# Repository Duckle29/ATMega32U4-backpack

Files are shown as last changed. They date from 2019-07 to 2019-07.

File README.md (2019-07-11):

This is a small backpack PCB, meant to go with some 2.4" I2C OLED LCD. It exposes ALL pins on the ATMega32U4, so can be used for pretty much anything.

## Pinout:

| Pin | Encoder |  UART  | I2C  | WS2812 | SPI | CS3V3 |
|:---:|:---:|:---:|:---:|:---:|:---:|:---:|
|  1  | GND | GND  | GND  | GND  | MISO | 3V3 shifted IO (B0) |
|  2  | B | TX-3V3 | 5V |  Data  | 3V3 | |
|  3  | A | RX | SCL-5V | 5V |  SCK-3V3 | |
|  4  | SW |  5V in | SDA-5V | | MOSI-3V3 | |
|  5  | | | | | Reset  | |
|  6  | | | | | GND | |

The remaining pins are broken out on the back, with their port and number listed.

On the bottom is a micro-B USB.

**R4 and R5**  
Are I2C pullups. Attach these only if no other I2C device has pullups on them already.

**R6 and R7**  
Are optional pull-ups for the encoder. These can help if you have a noisy signal due to the weak internal pullups of the IC.

**Power**  
If the board is powered through the USB, the 5v power limit is 100mA, as it passes through D1. This is done to enable the chip to test if it's powered through USB or not.

```C
bool has_usb(void) {
  /* return (UDADDR & _BV(ADDEN)); */
   USBCON |= (1 << OTGPADE); // enables VBUS pad
   _delay_us(5);
   return (USBSTA & (1<<VBUS));  // checks state of VBUS
}
```

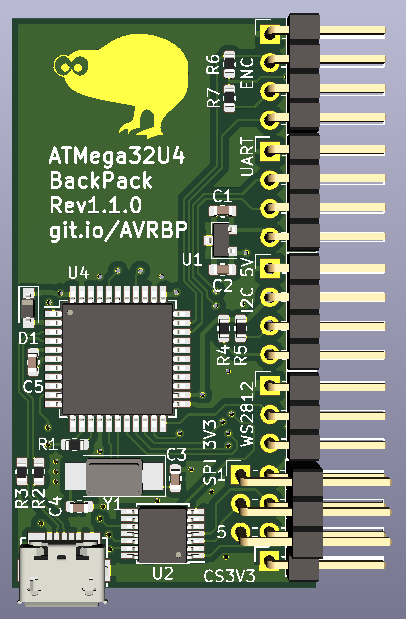
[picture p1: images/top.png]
top render

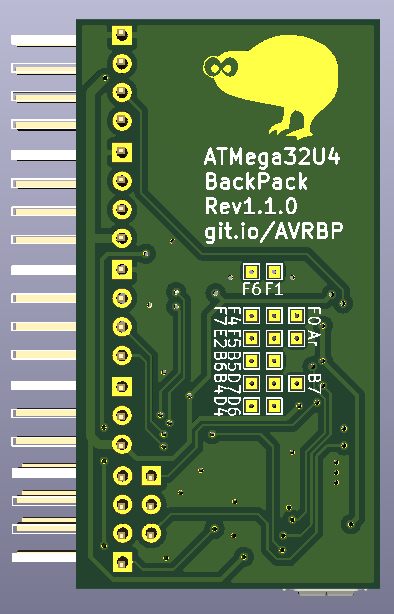
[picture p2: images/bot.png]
bot render


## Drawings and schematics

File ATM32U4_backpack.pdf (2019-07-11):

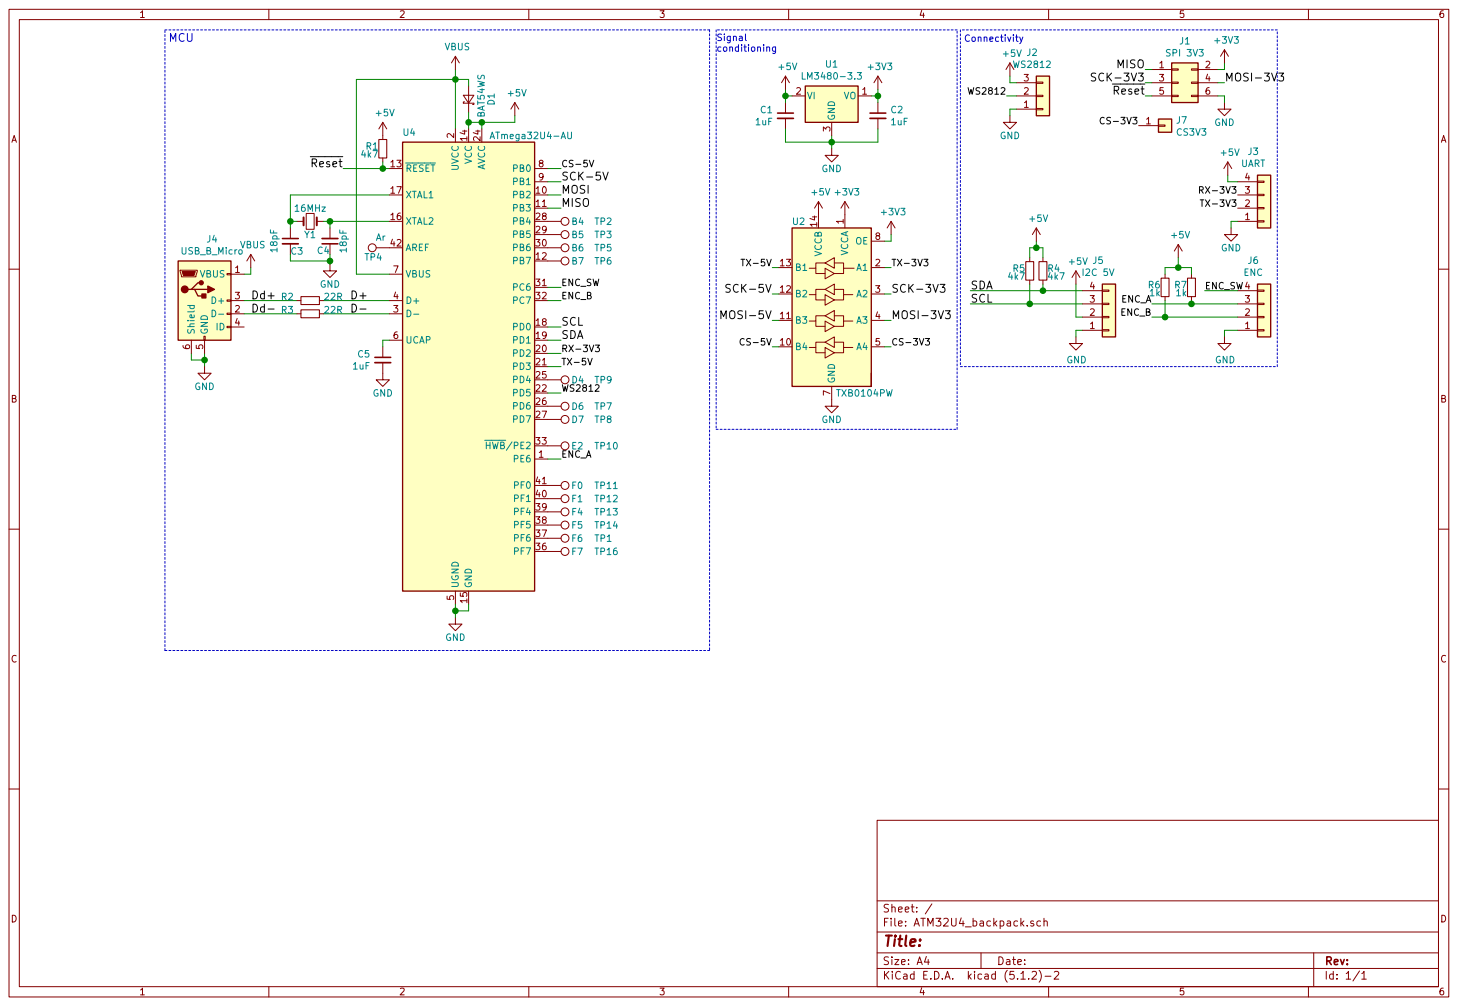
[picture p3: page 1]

2 PD2 20 PD3 21 PD5 22 AVCC 24 PD4 25 PD6 26 PD7 27 PB4 28 PB5 29 D- 3 PB6 30 PC6 31 PC7 32 HWB/PE2 33 PF7 36 PF6 37 PF5 38 PF4 39 D+ 4 PF1 40 PF0 41 AREF 42 UGND

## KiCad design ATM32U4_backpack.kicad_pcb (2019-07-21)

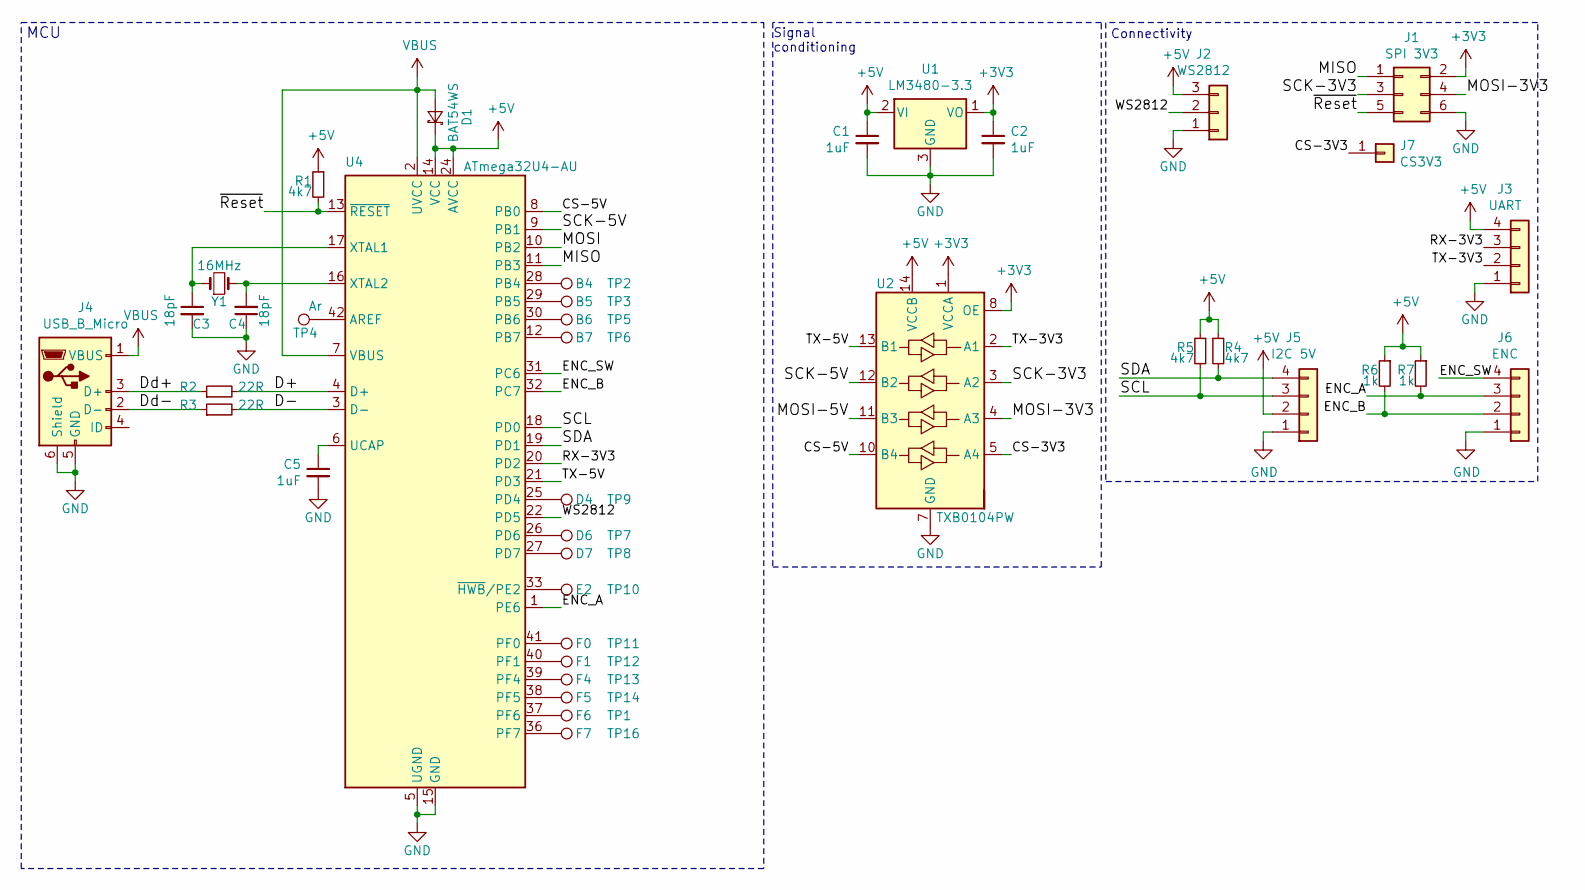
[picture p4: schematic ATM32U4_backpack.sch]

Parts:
C1, C2, C5: 1uF; C_0603_1608Metric
C3, C4: 18pF; C_0603_1608Metric
D1: BAT54WS; D_SOD-323_HandSoldering
J1: SPI 3V3; PinHeader_2x03_P2.54mm_Horizontal
J2: WS2812; PinHeader_1x03_P2.54mm_Horizontal
J3: UART; PinHeader_1x04_P2.54mm_Horizontal
J4: USB_B_Micro; USB_Micro-B_Molex_47346-0001
J5: I2C 5V; PinHeader_1x04_P2.54mm_Horizontal
J6: ENC; PinHeader_1x04_P2.54mm_Horizontal
J7: CS3V3; PinHeader_1x01_P2.54mm_Horizontal
R1, R4, R5: 4k7; R_0603_1608Metric
R2, R3: 22R; R_0603_1608Metric
R6, R7: 1k; R_0603_1608Metric
TP1: F6; TestPoint_Pad_1.0x1.0mm
TP2: B4; TestPoint_Pad_1.0x1.0mm
TP3: B5; TestPoint_Pad_1.0x1.0mm
TP4: Ar; TestPoint_Pad_1.0x1.0mm
TP5: B6; TestPoint_Pad_1.0x1.0mm
TP6: B7; TestPoint_Pad_1.0x1.0mm
TP7: D6; TestPoint_Pad_1.0x1.0mm
TP8: D7; TestPoint_Pad_1.0x1.0mm
TP9: D4; TestPoint_Pad_1.0x1.0mm
TP10: E2; TestPoint_Pad_1.0x1.0mm
TP11: F0; TestPoint_Pad_1.0x1.0mm
TP12: F1; TestPoint_Pad_1.0x1.0mm
TP13: F4; TestPoint_Pad_1.0x1.0mm
TP14: F5; TestPoint_Pad_1.0x1.0mm
TP16: F7; TestPoint_Pad_1.0x1.0mm
U1: LM3480-3.3; SOT-23
U2: TXB0104PW; TSSOP-14_4.4x5mm_P0.65mm
U4: ATmega32U4-AU; TQFP-44_10x10mm_P0.8mm
Y1: 16MHz; Crystal_SMD_5032-2Pin_5.0x3.2mm_HandSoldering

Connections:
+3V3: C2.1, J1.2, U1.1 (VO), U2.1 (VCCA), U2.8 (OE)
+5V: C1.1, D1.1 (K), J2.3, J3.4, J5.2, R1.1, R4.1, R5.1, R6.1, R7.1, U1.2 (VI), U2.14 (VCCB), U4.14 (VCC), U4.24 (AVCC), U4.34 (VCC), U4.44 (AVCC)
/CS-3V3: J7.1, U2.5 (A4)
/CS-5V: U2.10 (B4), U4.8 (PB0)
/D+: R2.2, U4.4 (D+)
/D-: R3.2, U4.3 (D-)
/Dd+: J4.3 (D+), R2.1
/Dd-: J4.2 (D-), R3.1
/ENC_A: J6.3, R7.2, U4.1 (PE6)
/ENC_B: J6.2, R6.2, U4.32 (PC7)
/ENC_SW: J6.4, U4.31 (PC6)
/MISO: J1.1, U4.11 (PB3)
/MOSI-3V3: J1.4, U2.4 (A3)
/RX-3V3: J3.3, U4.20 (PD2)
/SCK-3V3: J1.3, U2.3 (A2)
/SCK-5V: U2.12 (B2), U4.9 (PB1)
/SCL: J5.3, R5.2, U4.18 (PD0)
/SDA: J5.4, R4.2, U4.19 (PD1)
/TX-3V3: J3.2, U2.2 (A1)
/TX-5V: U2.13 (B1), U4.21 (PD3)
/WS2812: J2.2, U4.22 (PD5)
/~Reset: J1.5, R1.2, U4.13 (~RESET)
GND: C1.2, C2.2, C3.2, C4.1, C5.2, J1.6, J2.1, J3.1, J4.5 (GND), J4.6 (Shield), J5.1, J6.1, U1.3 (GND), U2.7 (GND), U4.5 (UGND), U4.15 (GND), U4.23 (GND), U4.35 (GND), U4.43 (GND)
unnamed: C3.1, U4.17 (XTAL1), Y1.1
unnamed: C4.2, U4.16 (XTAL2), Y1.2
unnamed: C5.1, U4.6 (UCAP)
unnamed: TP1.1, U4.37 (PF6)
unnamed: TP2.1, U4.28 (PB4)
unnamed: TP3.1, U4.29 (PB5)
unnamed: TP4.1, U4.42 (AREF)
unnamed: TP5.1, U4.30 (PB6)
unnamed: TP6.1, U4.12 (PB7)
unnamed: TP7.1, U4.26 (PD6)
unnamed: TP8.1, U4.27 (PD7)
unnamed: TP9.1, U4.25 (PD4)
unnamed: TP10.1, U4.33 (~HWB~/PE2)
unnamed: TP11.1, U4.41 (PF0)
unnamed: TP12.1, U4.40 (PF1)
unnamed: TP13.1, U4.39 (PF4)
unnamed: TP14.1, U4.38 (PF5)
unnamed: TP16.1, U4.36 (PF7)
VBUS: D1.2 (A), J4.1 (VBUS), U4.2 (UVCC), U4.7 (VBUS)

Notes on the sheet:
MCU
Signal conditioning
Connectivity

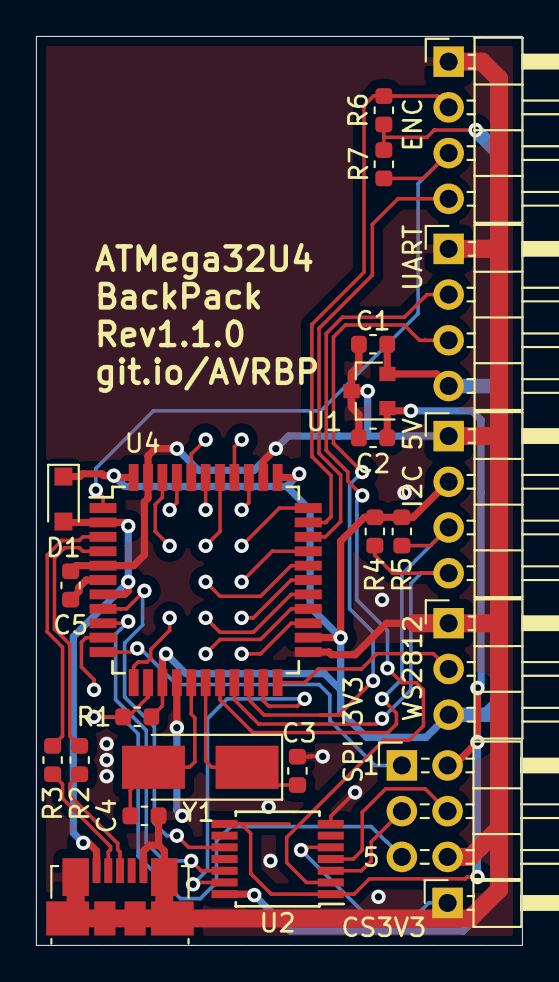
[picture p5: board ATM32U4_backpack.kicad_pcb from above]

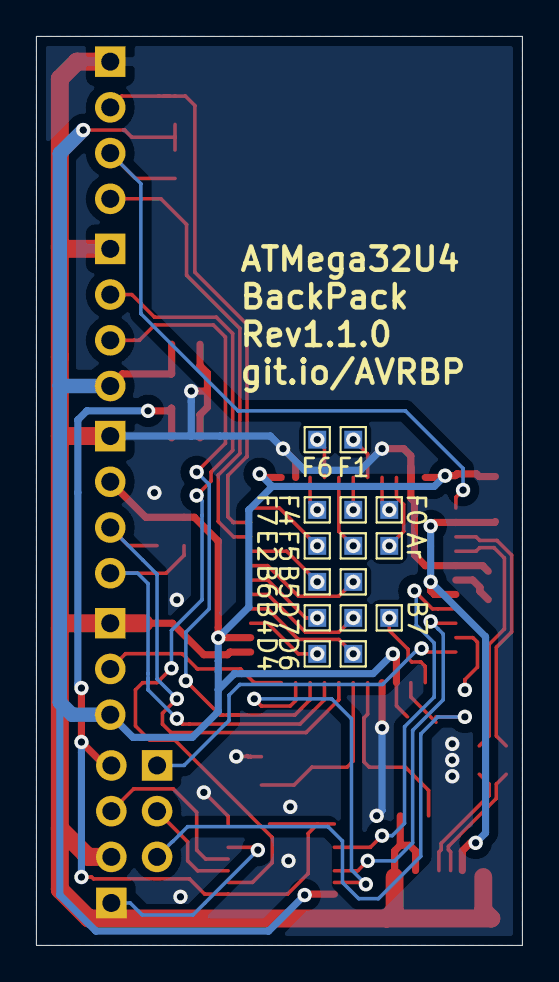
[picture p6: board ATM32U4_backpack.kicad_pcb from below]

Board: 2 copper layers, 27.0 x 50.5 mm, 39 parts (15 on the bottom side), 42 nets.

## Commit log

2019-07-10 Added License and expanded gitignore
    [ATM32U4_backpack.kicad_pcb]
2019-07-10 added schematic pdf and readme
    [ATM32U4_backpack.kicad_pcb]
2019-07-11 Added gerbers
    [ATM32U4_backpack-B_Cu.gbr, ATM32U4_backpack-B_Mask.gbr, ATM32U4_backpack-B_SilkS.gbr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]
2019-07-11 Fixed back silkscreen
    [ATM32U4_backpack.kicad_pcb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]
2019-07-11 Made SPI level-shifted to 3v3
    [ATM32U4_backpack-B_Cu.gbr, ATM32U4_backpack-B_Mask.gbr, ATM32U4_backpack-B_SilkS.gbr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]
2019-07-11 Added 3D model of crystal
    [ATM32U4_backpack.kicad_pcb]
2019-07-21 made the wiggly lines more pretty
    [ATM32U4_backpack-B_Cu.gbr, ATM32U4_backpack-B_Mask.gbr, ATM32U4_backpack-B_SilkS.gbr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]
